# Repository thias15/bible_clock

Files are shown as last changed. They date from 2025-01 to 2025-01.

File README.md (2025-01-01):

# Bible Clock

The goal of this project is to build a clock that displays a bible verse for each minute of the day. The reference corresponds the current time (chapter:verse <--> hour:minute).

## Quickstart

- Connect the e-ink display to the ESP32
- Add you ssid and password in the file main.cpp and flash the firmware
- Build and upload the filesystem image (use the verse database in the data folder - generated using ESV)

## Generate bible verse database

### Download a bible in json format

1) https://www.biblesupersearch.com/bible-downloads/

2) https://github.com/jadenzaleski/BibleTranslations

### Build bible verse database

The will build a database of bible verses for each minute of the day. It first sample verse candidates, then asks GPT for the best one. If no suitable verse is found, an encouraging statement is generated instead.

1) export OPENAI_API_KEY=<api_key>

2) Run the parser script

The example below is for the ESV bible from the jadenzaleski repository.
```
python parser.py jadenzaleski esv.json
```

## Firmware

### Dependencies

- ArduinoJson

### Program ESP32

1) Make sure to update ssid and password in main.cpp
2) Compile and flash the firmware to the ESP32
3) Make sure a json file for each hour is located in the data folder
4) In the project tasks: 
    - esp32dev --> Platform --> Build Filesystem Image
    - esp32dev --> Platform --> Upload Filesystem Image

## Assembly

### 3D-printed clock chassis

- [Chassis](cad/chassis.step)
- [Lid](cad/lid.step)

### Wiring

- BUSY to PIN 25
- RST to PIN 26
- DC to PIN 27
- CS to PIN 15
- SCLK to PIN 13
- DIN to PIN 14
- GND to GND
- VCC to 3.3V

## Generate new fonts

https://github.com/zst-embedded/STM32-LCD_Font_Generator.git

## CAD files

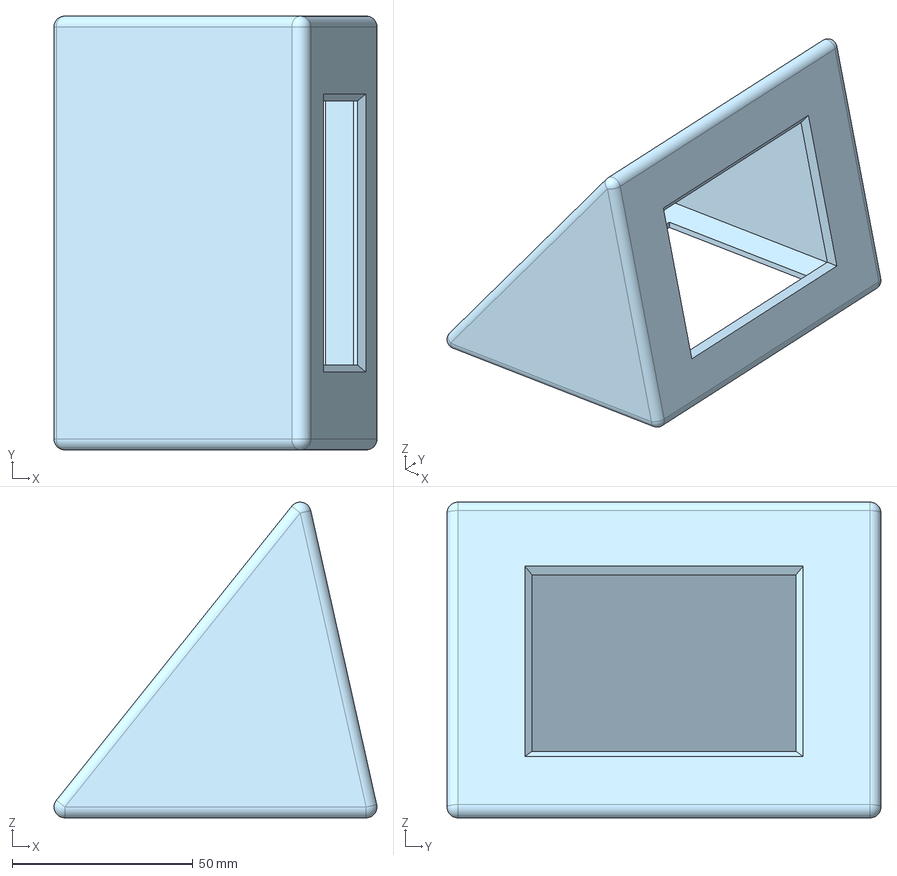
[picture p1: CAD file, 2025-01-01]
cad/chassis.step
89.3 x 120.0 x 87.3 mm

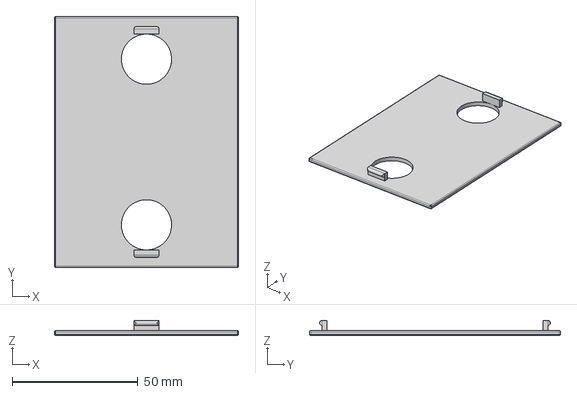
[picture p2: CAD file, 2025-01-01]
cad/lid.step
73.3 x 100.0 x 6.00 mm

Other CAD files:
cad/chassis.stl
cad/lid.stl

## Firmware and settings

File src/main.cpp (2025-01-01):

#include <Arduino.h>
#include <WiFi.h>
#include <HTTPClient.h>
#include <ArduinoJson.h>
#include <FS.h>
#include <SPIFFS.h>
#include <time.h>
#include <esp_sleep.h>

// E-paper libraries
#include "EPD_3in52b.h"
#include "GUI_Paint.h"
#include "fonts.h"
#include "ImageData.h"

// ---------------------------- Configuration ----------------------------

// WiFi credentials
const char* ssid = "";       // <-- Replace with your WiFi SSID
const char* password = ""; // <-- Replace with your WiFi Password

// NTP Configuration
const char* ntpServer = "pool.ntp.org";
const long  gmtOffset_sec = 3600;       // UTC+1
const int   daylightOffset_sec = 3600;  // DST offset if applicable

// e-Paper
UBYTE *BlackImage;
UBYTE *RedImage;

// Timing Variables
unsigned long previousDisplayUpdateMillis = 0;
unsigned long previousTimeSyncMillis = 0;
const unsigned long displayUpdateIntervalMs = 60000UL;  // Update display every 60 seconds after the first update
int lastSyncedHour = -1;

// JSON Document for the current hour's verses
// Reduced size based on estimation. Adjust as needed.
StaticJsonDocument<100000> hourDoc;

// Track the last loaded hour to prevent redundant loads
int lastLoadedHour = -1;

// Display Dimensions (Adjust based on your e-Paper display)
const int displayWidth = EPD_3IN52B_HEIGHT - 5;  // Leave 5 pixels free on the right
const int displayHeight = EPD_3IN52B_WIDTH;

// --------------------------------------------------------------------
// 1) Initialize WiFi
// --------------------------------------------------------------------
void initWiFi() {
    Serial.print("Connecting to ");
    Serial.println(ssid);
    WiFi.begin(ssid, password);
    unsigned long wifiStart = millis();
    
    while (WiFi.status() != WL_CONNECTED) {
        delay(500);
        Serial.print(".");
        // Timeout after 30 seconds
        if (millis() - wifiStart > 30000UL) {
            Serial.println("\nFailed to connect to WiFi.");
            // Optionally, implement retry logic or enter a safe mode
            return;
        }
    }
    
    Serial.println("\nWiFi connected");
    Serial.print("IP Address: ");
    Serial.println(WiFi.localIP());
}

// --------------------------------------------------------------------
// 2) Initialize Time via NTP
// --------------------------------------------------------------------
bool syncTime() {
    configTime(gmtOffset_sec, daylightOffset_sec, ntpServer);
    Serial.println("Synchronizing time with NTP...");
    
    struct tm timeinfo;
    unsigned long syncStart = millis();
    const unsigned long syncTimeout = 10000UL; // 10 seconds timeout
    
    while (!getLocalTime(&timeinfo)) {
        delay(500);
        Serial.print(".");
        if (millis() - syncStart > syncTimeout) {
            Serial.println("\nTime synchronization failed.");
            return false;
        }
    }
    
    Serial.println("\nTime synchronized");
    return true;
}

// --------------------------------------------------------------------
// 3) Load JSON for the given hour from SPIFFS
//    e.g., hour=3 -> "/bible_verses_hour03.json"
// --------------------------------------------------------------------
bool loadBibleVersesForHour(int hour) {
    // Clear previous JSON data
    hourDoc.clear();

    // Initialize SPIFFS
    if (!SPIFFS.begin(true)) { 
        Serial.println("SPIFFS Mount Failed");
        return false;
    }

    // Build the filename, e.g., "/bible_verses_hour03.json" for hour=3
    // If hour=0, treat it as 24 in the calling code
    char filename[32];
    snprintf(filename, sizeof(filename), "/bible_verses_hour%02d.json", hour);
    
    File file = SPIFFS.open(filename, "r");
    if (!file) {
        Serial.print("Failed to open file for hour = ");
        Serial.println(hour);
        return false;
    }

    // Deserialize JSON
    DeserializationError error = deserializeJson(hourDoc, file);
    file.close();
    if (error) {
        Serial.print("Failed to parse JSON for hour = ");
        Serial.print(hour);
        Serial.print(": ");
        Serial.println(error.c_str());
        return false;
    }

    Serial.print("Loaded verses for hour ");
    Serial.println(hour);
    return true;
}

// --------------------------------------------------------------------
// 4) Retrieve both reference and verse based on a single time fetch
// --------------------------------------------------------------------
struct VerseData {
    String reference;
    String text;
};

// Helper function to extract the book name from the reference string with parentheses ()
String extractBookName(const String &reference) {
    int start = reference.indexOf('(');
    int end = reference.indexOf(')');
    if (start != -1 && end != -1 && end > start) {
        String insideParentheses = reference.substring(start + 1, end);
        return "[" + insideParentheses + "]"; // If no space, return the whole string with brackets
    }
    return ""; // Return empty string if format is unexpected
}

VerseData getCurrentVerseData(const struct tm &timeinfo) {
    VerseData data;
    
    int hour = timeinfo.tm_hour;
    int minute = timeinfo.tm_min;

    // If hour=0, treat as 24
    if (hour == 0) hour = 24;

    // Load JSON for the current hour if not already loaded
    if (hour != lastLoadedHour) {
        if (!loadBibleVersesForHour(hour)) {
            Serial.println("Failed to load data for this hour.");
            return data;  // Return empty data
        }
        lastLoadedHour = hour;
    }

    // Build minute as two-digit string: "00".."59"
    char minuteStr[3];
    snprintf(minuteStr, sizeof(minuteStr), "%02d", minute);

    // Retrieve reference and text from JSON
    JsonObject entry = hourDoc[minuteStr];
    if (!entry.isNull()) {
        if (entry.containsKey("reference") && entry.containsKey("text")) {
            String fullReference = entry["reference"].as<String>();
            data.reference = extractBookName(fullReference); // Now includes brackets
            data.text = entry["text"].as<String>();
        } else {
            Serial.print("Missing 'reference' or 'text' in JSON for minute ");
            Serial.println(minuteStr);
        }
    } else {
        Serial.print("No entry found in JSON for minute ");
        Serial.println(minuteStr);
    }

    return data;
}

// --------------------------------------------------------------------
// 5) Display Content: Time, Reference, and Verse
// --------------------------------------------------------------------
void displayContent(const String &currentTimeStr, const String &reference, const String &verseText) {
    // Clear both images
    Paint_SelectImage(RedImage);
    Paint_Clear(WHITE);  // Clear with white background
    // Draw Time at Top Center with Font32 in Red on White Background
    int timeTextLength = currentTimeStr.length(); // Should be 5 for "HH:MM"
    int timeFontWidth = Font32.Width * timeTextLength;
    int timeX = (displayWidth - timeFontWidth) / 2;
    Paint_DrawString_EN(timeX, 10, currentTimeStr.c_str(), &Font32, WHITE, RED);

    // Draw Reference Book if available
    if (!reference.isEmpty()) {
        int refTextLength = reference.length(); // Should include brackets, e.g., "(John)"
        int refFontWidth = Font20.Width * refTextLength;
        int refX = (displayWidth - refFontWidth) / 2; // Center horizontally
        Paint_DrawString_EN(refX, 50, reference.c_str(), &Font20, WHITE, RED);
    }

    // Determine appropriate font size for verse based on length
    sFONT *verseFont;
    if (verseText.length() < 80) {
        verseFont = &Font24;
    } else if (verseText.length() < 120) {
        verseFont = &Font20;
    } else if (verseText.length() < 240) {
        verseFont = &Font16;
    } else {
        verseFont = &Font12;
    }

    Paint_SelectImage(BlackImage);
    Paint_Clear(WHITE);  // Clear with white background
    // Calculate verse position
    int verseX = 10; // Starting X position with some padding
    int verseY = reference.isEmpty() ? 60 : 90; // Adjust Y based on whether reference is present

    // Wrap and center the verse text
    // Assuming Paint_DrawString_EN_WordWrap handles wrapping based on font size and display width
    Paint_DrawString_EN_WordWrap(verseX, verseY, verseText.c_str(), verseFont, WHITE, BLACK, 2);

    // Update e-Paper Display
    EPD_3IN52B_Display(BlackImage, RedImage);   // Red layer
    Serial.println("Display updated.");
}

// --------------------------------------------------------------------
// 6) Update display with time and corresponding bible verse
// --------------------------------------------------------------------
void updateDisplay() {
  struct tm currentTime;
  if (getLocalTime(&currentTime)) { // Refresh time after delay
      struct tm frozenTimeinfo = currentTime; // Freeze timeinfo immediately
      char timeBuffer[6]; // HH:MM
      snprintf(timeBuffer, sizeof(timeBuffer), "%02d:%02d", frozenTimeinfo.tm_hour, frozenTimeinfo.tm_min);
      String currentTimeStr = String(timeBuffer);
      VerseData verse = getCurrentVerseData(frozenTimeinfo);
      if (!verse.reference.isEmpty() || !verse.text.isEmpty()) {
          displayContent(currentTimeStr, verse.reference, verse.text);
      } else {
          Serial.println("Initial verse data is empty. Skipping display.");
      }
  } else {
      Serial.println("Failed to retrieve current time.");
  }
}

// --------------------------------------------------------------------
// 7) Calculate Milliseconds Until Next Minute
// --------------------------------------------------------------------
unsigned long millisUntilNextMinute(const struct tm &timeinfo) {
    int seconds = timeinfo.tm_sec;
    int millisec = millis() % 1000;
    unsigned long remainingSeconds = 59 - seconds;
    unsigned long remainingMillis = 1000 - millisec;
    return (remainingSeconds * 1000UL) + remainingMillis;
}

// --------------------------------------------------------------------
// 8) Check for time sync at the beginning of each new hour
// --------------------------------------------------------------------
void checkTimeSync() {
    struct tm timeinfo;
    if (!getLocalTime(&timeinfo)) {
        Serial.println("Failed to retrieve current time.");
        return;
    }

    // Check if the hour has changed since the last sync
    if (timeinfo.tm_hour != lastSyncedHour) {
        lastSyncedHour = timeinfo.tm_hour;  // Update the last synced hour

        if (WiFi.status() == WL_CONNECTED) {
            Serial.println("Beginning of a new hour detected. Syncing time...");
            if (syncTime()) {   // Perform the time sync
                updateDisplay(); // Update the display immediately after sync
            }
        } else {
            Serial.println("WiFi not connected. Cannot synchronize time.");
        }
    }
}

// --------------------------------------------------------------------
// Setup
// --------------------------------------------------------------------
void setup() {
    Serial.begin(115200);
    delay(1000); // Allow time for Serial to initialize

    // Initialize WiFi
    initWiFi();

    // Initialize Time
    if (!syncTime()) {
        Serial.println("Initial time synchronization failed. Continuing without accurate time.");
        // Optionally, handle this scenario (e.g., retry, use fallback time, etc.)
    }

    // Initialize e-Paper Module
    DEV_Module_Init();
    EPD_3IN52B_Init();
    EPD_3IN52B_Clear();
    DEV_Delay_ms(1000);

    // Allocate memory for e-Paper buffers
    UWORD Imagesize = ((EPD_3IN52B_WIDTH % 8 == 0) 
                        ? (EPD_3IN52B_WIDTH / 8) 
                        : (EPD_3IN52B_WIDTH / 8 + 1)) 
                        * EPD_3IN52B_HEIGHT;
    BlackImage = (UBYTE *)malloc(Imagesize);
    RedImage   = (UBYTE *)malloc(Imagesize);
    if (!BlackImage || !RedImage) {
        Serial.println("Failed to allocate memory for images");
        while (true); // Halt execution
    }

    // Initialize Paint for Black and Red Images
    Paint_NewImage(BlackImage, EPD_3IN52B_WIDTH, EPD_3IN52B_HEIGHT, 90, WHITE);
    Paint_SelectImage(BlackImage);
    Paint_Clear(WHITE);

    Paint_NewImage(RedImage, EPD_3IN52B_WIDTH, EPD_3IN52B_HEIGHT, 90, WHITE);
    Paint_SelectImage(RedImage);
    Paint_Clear(WHITE);

    // Retrieve current time
    struct tm currentTime;
    if (!getLocalTime(&currentTime)) {
      Serial.println("Failed to retrieve current time.");
      displayContent("0:00", "WiFi Error", "Display will not update until time is synchronized.");
    } else {
        unsigned long currentMs = millis();
        checkTimeSync();
        updateDisplay();
        unsigned long timeElapsedMs = millis() - currentMs;        
        // Calculate milliseconds until the next minute starts
        unsigned long initialDelay = millisUntilNextMinute(currentTime) - timeElapsedMs;
        // Wait until one second after the next minute before the first regular update
        delay(initialDelay + 1000UL);
        updateDisplay();
    }

    // Initialize timing variables
    previousDisplayUpdateMillis = millis();
    previousTimeSyncMillis = millis();
}

// --------------------------------------------------------------------
// Loop
// --------------------------------------------------------------------
void loop() {
    unsigned long currentMs = millis();

    // Check for time sync at the start of the hour
    checkTimeSync();

    // Update display
    updateDisplay();

    // Measure elapsed time
    unsigned long timeElapsedMs = millis() - currentMs;
    unsigned long remainingMs = displayUpdateIntervalMs - timeElapsedMs;
    Serial.print("Going to light sleep for ");
    Serial.print(remainingMs);
    Serial.println(" milliseconds...");
    delay(remainingMs);

    // // Limit sleep to 5 seconds (5000 ms) at a time
    // while (remainingMs > 0) {
    //     unsigned long sleepMs = min(remainingMs, 5000UL); // Sleep for 5 seconds or remaining time
    //     remainingMs -= sleepMs;
    //     // Needed so powerbank does not turn off
    //     if (sleepMs > 1000UL) {
    //         delay(1000UL);
    //         sleepMs -= 1000UL;
    //     }      
    //     uint64_t sleepUs = sleepMs * 1000; // Convert to microseconds

    //     // Enable timer wakeup
    //     esp_sleep_enable_timer_wakeup(sleepUs);
    //     esp_light_sleep_start();
    // }
}

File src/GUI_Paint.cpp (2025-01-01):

/******************************************************************************
* | File      	:   GUI_Paint.c
* | Author      :   Waveshare electronics
* | Function    :	Achieve drawing: draw points, lines, boxes, circles and
*                   their size, solid dotted line, solid rectangle hollow
*                   rectangle, solid circle hollow circle.
* | Info        :
*   Achieve display characters: Display a single character, string, number
*   Achieve time display: adaptive size display time minutes and seconds
*----------------
* |	This version:   V3.2
* | Date        :   2020-07-23
* | Info        :
* -----------------------------------------------------------------------------
* V3.2(2020-07-23):
* 1. Change: Paint_SetScale(UBYTE scale)
*			Add scale 7 for 5.65f e-Parper
* 2. Change: Paint_SetPixel(UWORD Xpoint, UWORD Ypoint, UWORD Color)  
* 			Add the branch for scale 7
* 3. Change: Paint_Clear(UWORD Color)
*			Add the branch for scale 7
*
* V3.1(2019-10-10):
* 1. Add gray level
*   PAINT Add Scale
* 2. Add void Paint_SetScale(UBYTE scale);
*
* V3.0(2019-04-18):
* 1.Change: 
*    Paint_DrawPoint(..., DOT_STYLE DOT_STYLE)
* => Paint_DrawPoint(..., DOT_STYLE Dot_Style)
*    Paint_DrawLine(..., LINE_STYLE Line_Style, DOT_PIXEL Dot_Pixel)
* => Paint_DrawLine(..., DOT_PIXEL Line_width, LINE_STYLE Line_Style)
*    Paint_DrawRectangle(..., DRAW_FILL Filled, DOT_PIXEL Dot_Pixel)
* => Paint_DrawRectangle(..., DOT_PIXEL Line_width, DRAW_FILL Draw_Fill)
*    Paint_DrawCircle(..., DRAW_FILL Draw_Fill, DOT_PIXEL Dot_Pixel)
* => Paint_DrawCircle(..., DOT_PIXEL Line_width, DRAW_FILL Draw_Filll)
*
* -----------------------------------------------------------------------------
* V2.0(2018-11-15):
* 1.add: Paint_NewImage()
*    Create an image's properties
* 2.add: Paint_SelectImage()
*    Select the picture to be drawn
* 3.add: Paint_SetRotate()
*    Set the direction of the cache    
* 4.add: Paint_RotateImage() 
*    Can flip the picture, Support 0-360 degrees, 
*    but only 90.180.270 rotation is better
* 4.add: Paint_SetMirroring() 
*    Can Mirroring the picture, horizontal, vertical, origin
* 5.add: Paint_DrawString_CN() 
*    Can display Chinese(GB1312)   
*
* ----------------------------------------------------------------------------- 
* V1.0(2018-07-17):
*   Create library
*
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
******************************************************************************/
#include "GUI_Paint.h"
#include <stdint.h>
#include <stdlib.h>
#include <string.h> //memset()
#include <math.h>

PAINT Paint;

/******************************************************************************
function: Create Image
parameter:
    image   :   Pointer to the image cache
    width   :   The width of the picture
    Height  :   The height of the picture
    Color   :   Whether the picture is inverted
******************************************************************************/
void Paint_NewImage(UBYTE *image, UWORD Width, UWORD Height, UWORD Rotate, UWORD Color)
{
    Paint.Image = NULL;
    Paint.Image = image;

    Paint.WidthMemory = Width;
    Paint.HeightMemory = Height;
    Paint.Color = Color;    
    Paint.Scale = 2;
    Paint.WidthByte = (Width % 8 == 0)? (Width / 8 ): (Width / 8 + 1);
    Paint.HeightByte = Height;    
//    printf("WidthByte = %d, HeightByte = %d\r\n", Paint.WidthByte, Paint.HeightByte);
//    printf(" EPD_WIDTH / 8 = %d\r\n",  122 / 8);
   
    Paint.Rotate = Rotate;
    Paint.Mirror = MIRROR_NONE;
    
    if(Rotate == ROTATE_0 || Rotate == ROTATE_180) {
        Paint.Width = Width;
        Paint.Height = Height;
    } else {
        Paint.Width = Height;
        Paint.Height = Width;
    }
}

/******************************************************************************
function: Select Image
parameter:
    image : Pointer to the image cache
******************************************************************************/
void Paint_SelectImage(UBYTE *image)
{
    Paint.Image = image;
}

/******************************************************************************
function: Select Image Rotate
parameter:
    Rotate : 0,90,180,270
******************************************************************************/
void Paint_SetRotate(UWORD Rotate)
{
    if(Rotate == ROTATE_0 || Rotate == ROTATE_90 || Rotate == ROTATE_180 || Rotate == ROTATE_270) {
        // Debug("Set image Rotate %d\r\n", Rotate);
        Paint.Rotate = Rotate;
    } else {
        Debug("rotate = 0, 90, 180, 270\r\n");
    }
}

/******************************************************************************
function:	Select Image mirror
parameter:
    mirror   :Not mirror,Horizontal mirror,Vertical mirror,Origin mirror
******************************************************************************/
void Paint_SetMirroring(UBYTE mirror)
{
    if(mirror == MIRROR_NONE || mirror == MIRROR_HORIZONTAL || 
        mirror == MIRROR_VERTICAL || mirror == MIRROR_ORIGIN) {
        // Debug("mirror image x:%s, y:%s\r\n",(mirror & 0x01)? "mirror":"none", ((mirror >> 1) & 0x01)? "mirror":"none");
        Paint.Mirror = mirror;
    } else {
        Debug("mirror should be MIRROR_NONE, MIRROR_HORIZONTAL, \
        MIRROR_VERTICAL or MIRROR_ORIGIN\r\n");
    }    
}

void Paint_SetScale(UBYTE scale)
{
    if(scale == 2){
        Paint.Scale = scale;
        Paint.WidthByte = (Paint.WidthMemory % 8 == 0)? (Paint.WidthMemory / 8 ): (Paint.WidthMemory / 8 + 1);
    }
	else if(scale == 4) {
        Paint.Scale = scale;
        Paint.WidthByte = (Paint.WidthMemory % 4 == 0)? (Paint.WidthMemory / 4 ): (Paint.WidthMemory / 4 + 1);
    }
	else if(scale == 6 || scale == 7) {//Only applicable with 5in65 e-Paper
		Paint.Scale = 7;
		Paint.WidthByte = (Paint.WidthMemory % 2 == 0)? (Paint.WidthMemory / 2 ): (Paint.WidthMemory / 2 + 1);
	}
	else {
        Debug("Set Scale Input parameter error\r\n");
        Debug("Scale Only support: 2 4 7\r\n");
    }
}
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

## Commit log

2025-01-01 add cad files
    [chassis.step, lid.step]
2025-01-01 add stl files
    [chassis.stl, lid.stl]
